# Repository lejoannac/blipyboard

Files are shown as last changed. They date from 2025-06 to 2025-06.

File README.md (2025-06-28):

# blipyboard
An 8 key macropad with an OLED screen and potentiometer for HackPad. It also has 8 SK6812 leds for lighting and utilizes custom KMK firmware. <br>

Screenshot 2025-06-27 at 11 23 31 PM

# **CAD Model**
Screenshot 2025-06-27 at 9 58 29 PM<br>
Designed and Modeled using Fusion 360

# **Schematic**
Screenshot 2025-06-27 at 10 01 06 PM

# **PCB**
Screenshot 2025-06-27 at 10 17 19 PM<br>
Schematic and PCB created using KiCad

# **BOM**
8x Cherry MX Switches<br>
9x 1N4148 Diodes<br>
8x SK6812 Mini LED<br>
8x Keycaps<br>
1x Rotary Encoder with push button<br>
1x 0.91" OLED Display (128x32)<br>
1x XIAO-RP2040 microcontroller<br>
4x M3x10mm screws<br>
1x Custom PCB<br>
1x 1kg spool of white filament from Amazon<br>
I will print my own case

# **Inspiration/Challenges**
I created this macropad to learn more about hardware and firmware creation. I wanted to be able to perform my most used functions with singular key presses such as copy/paste and inserting long strings. While working on this hackpad, I encountered issues with the firmware, the pcb, and 3d models associated with the footprints. By looking at other people's submissions and asking for help on slack, I overcame these issues. In the future I want to learn how to integrate QMK firmware and add more advanced animations for the OLED.

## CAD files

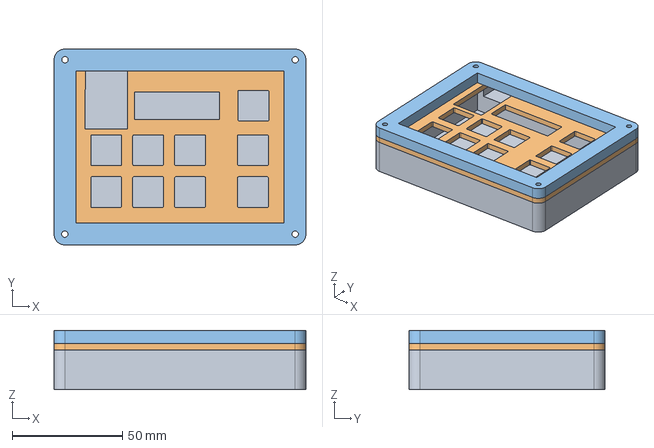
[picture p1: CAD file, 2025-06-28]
cad/blipyboard_complete.step
114.5 x 89.1 x 27.0 mm

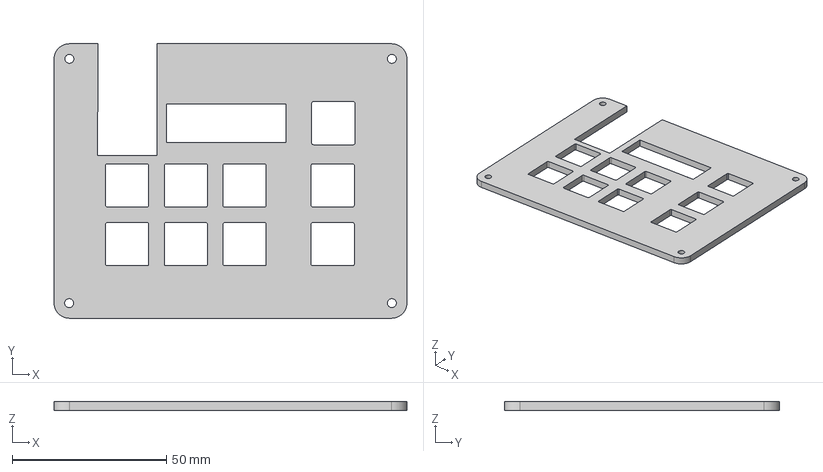
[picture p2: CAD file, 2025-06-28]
cad/plate.step
114.5 x 89.1 x 3.00 mm

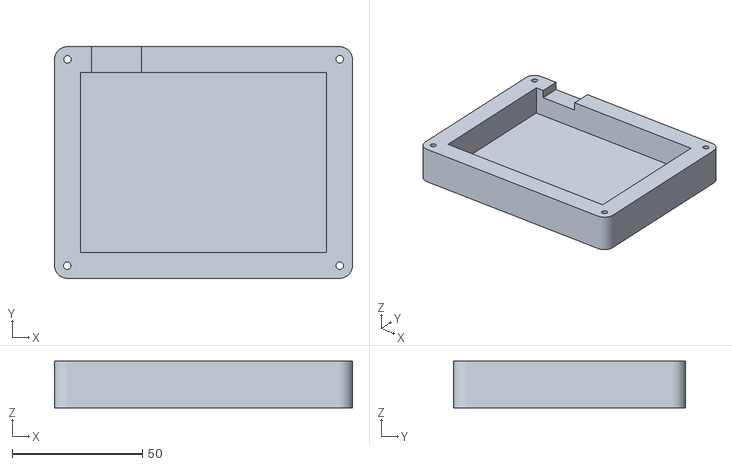
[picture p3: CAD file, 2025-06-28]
production/bottom.stl
114.5 x 89.1 x 18.0

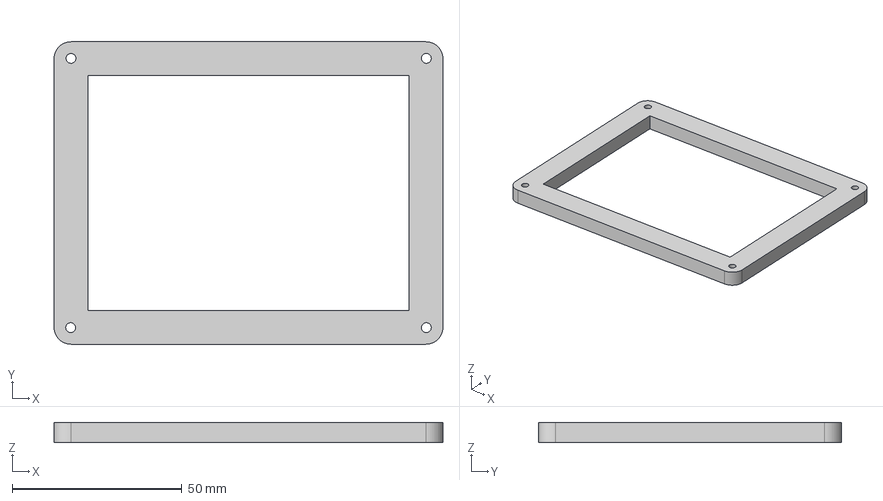
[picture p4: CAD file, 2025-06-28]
cad/top.step
114.5 x 89.1 x 6.00 mm

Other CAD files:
production/plate.stl
production/top.stl
cad/bottom.step

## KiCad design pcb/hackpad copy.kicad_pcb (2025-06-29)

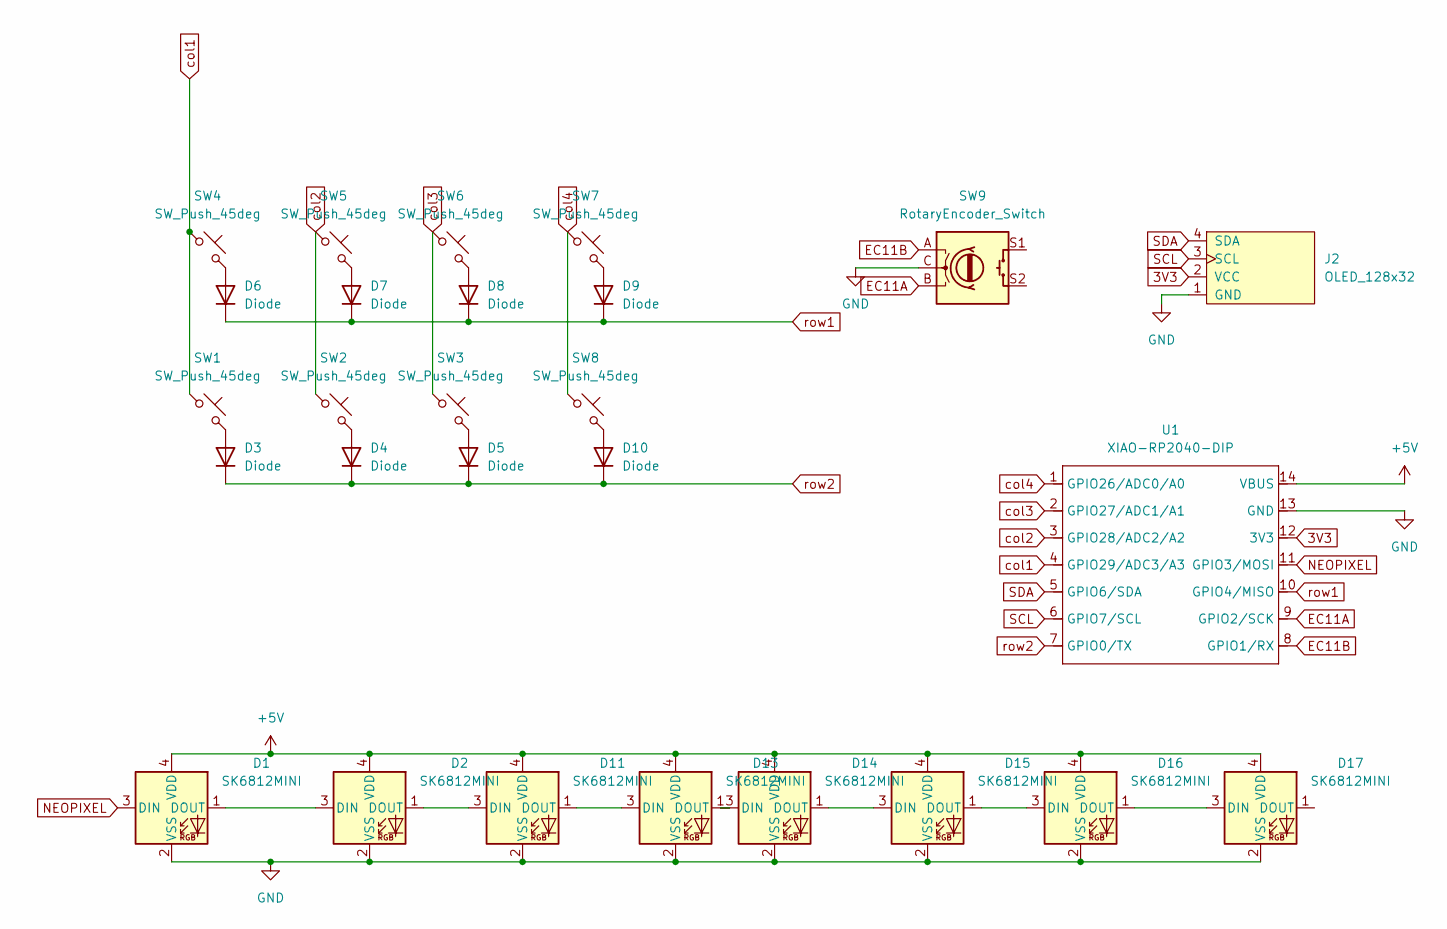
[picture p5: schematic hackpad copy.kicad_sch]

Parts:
D1, D2, D11, D13, D14, D15, D16, D17: SK6812MINI; LED_SK6812MINI_PLCC4_3.5x3.5mm_P1.75mm
D3, D4, D5, D6, D7, D8, D9, D10: Diode; D_DO-35_SOD27_P7.62mm_Horizontal
J2: OLED_128x32
SW1, SW2, SW3, SW4, SW5, SW6, SW7, SW8: SW_Push_45deg; SW_Cherry_MX_1.00u_PCB
SW9: RotaryEncoder_Switch; RotaryEncoder_Alps_EC11E-Switch_Vertical_H20mm
U1: XIAO-RP2040-DIP

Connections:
3V3: J2.2 (VCC), U1.12 (3V3)
+5V: D1.4 (VDD), D2.4 (VDD), D11.4 (VDD), D13.4 (VDD), D14.4 (VDD), D15.4 (VDD), D16.4 (VDD), D17.4 (VDD), U1.14 (VBUS)
EC11A: SW9.B, U1.9 (GPIO2/SCK)
EC11B: SW9.A, U1.8 (GPIO1/RX)
GND: D1.2 (VSS), D2.2 (VSS), D11.2 (VSS), D13.2 (VSS), D14.2 (VSS), D15.2 (VSS), D16.2 (VSS), D17.2 (VSS), J2.1 (GND), SW9.C, U1.13 (GND)
NEOPIXEL: D1.3 (DIN), U1.11 (GPIO3/MOSI)
unnamed: D1.1 (DOUT), D2.3 (DIN)
unnamed: D3.2 (A), SW1.2
unnamed: D4.2 (A), SW2.2
unnamed: D5.2 (A), SW3.2
unnamed: D6.2 (A), SW4.2
unnamed: D7.2 (A), SW5.2
unnamed: D8.2 (A), SW6.2
unnamed: D9.2 (A), SW7.2
unnamed: D10.2 (A), SW8.2
unnamed: D2.1 (DOUT), D11.3 (DIN)
unnamed: D11.1 (DOUT), D13.3 (DIN)
unnamed: D13.1 (DOUT), D14.3 (DIN)
unnamed: D14.1 (DOUT), D15.3 (DIN)
unnamed: D15.1 (DOUT), D16.3 (DIN)
unnamed: D16.1 (DOUT), D17.3 (DIN)
SCL: J2.3 (SCL), U1.6 (GPIO7/SCL)
SDA: J2.4 (SDA), U1.5 (GPIO6/SDA)
col1: SW1.1, SW4.1, U1.4 (GPIO29/ADC3/A3)
col2: SW2.1, SW5.1, U1.3 (GPIO28/ADC2/A2)
col3: SW3.1, SW6.1, U1.2 (GPIO27/ADC1/A1)
col4: SW7.1, SW8.1, U1.1 (GPIO26/ADC0/A0)
row1: D6.1 (K), D7.1 (K), D8.1 (K), D9.1 (K), U1.10 (GPIO4/MISO)
row2: D3.1 (K), D4.1 (K), D5.1 (K), D10.1 (K), U1.7 (GPIO0/TX)

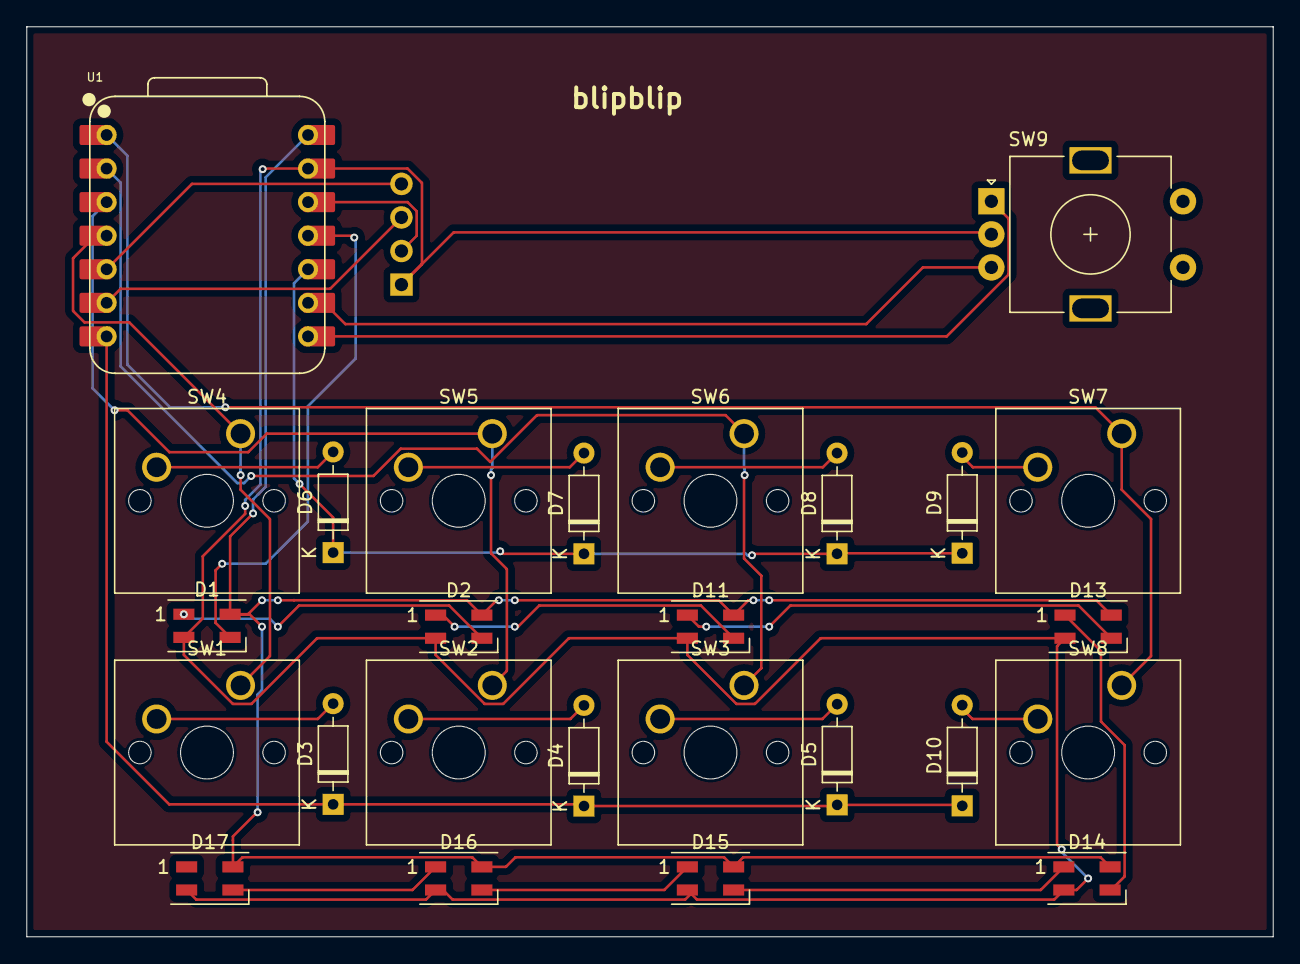
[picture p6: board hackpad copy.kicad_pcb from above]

Board: 2 copper layers, 94.3 x 68.9 mm, 27 parts (0 on the bottom side), 29 nets.

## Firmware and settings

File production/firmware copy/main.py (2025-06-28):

# You import all the IOs of your board
import board
import busio

# These are imports from the kmk library
from kmk.kmk_keyboard import KMKKeyboard
from kmk.scanners.keypad import KeysScanner
from kmk.keys import KC
from kmk.modules.macros import Press, Release, Tap, Macros
from kmk.modules.encoder import EncoderHandler
from kmk.extensions.mouse_keys import MouseKeys
from kmk.extensions.rgb import RGB
from kmk.extensions.display.ssd1306 import SSD1306
from kmk.extensions.display import Display, ImageEntry, TextEntry
from kmk.scanners.matrix import MatrixScanner


col1 = board.GP29
col2 = board.GP28
col3 = board.GP27
col4 = board.GP26
row1 = board.GP4
row2 = board.GP0
SDA = board.GP6
SCL = board.GP7
EC11A = board.GP2
EC11B = board.GP1

# This is the main instance of your keyboard
keyboard = KMKKeyboard()
mouse_keys = MouseKeys()
keyboard.extensions.append(mouse_keys)

# Add the macro extension
macros = Macros()
keyboard.modules.append(macros)

encoder_handler = EncoderHandler()

keyboard.modules.append(encoder_handler)
encoder_handler.pins = ((EC11A, EC11B),)
encoder_handler.map = [((KC.VOLU, KC.VOLD),)]

rgb = RGB(pixel_pin=board.GP3, 
          num_pixels=8, 
          rgb_order=(1,0,2),
          
          )
keyboard.extensions.append(rgb)

i2c_bus = busio.I2C(SCL, SDA)
driver = SSD1306(i2c=i2c_bus)

display = Display(
    # Mandatory:
    display=driver,
    # Optional:
    width=128, # screen size
    height=32, # screen size
    flip = False, # flips your display content
    flip_left = False, # flips your display content on left side split
    flip_right = False, # flips your display content on right side split
    brightness=1, # initial screen brightness level
)

display.entries = [
    ImageEntry(image="me.bmp", x=0, y=0, layer=0),
]
keyboard.extensions.append(display)


# Define your pins here!
ROW_PINS = [row1, row2]
COL_PINS = [col1, col2, col3, col4]


keyboard.matrix = MatrixScanner(
    columns=COL_PINS,
    rows=ROW_PINS,
)

keyboard.keymap = [
    [
        KC.MPRV, KC.MPLY, KC.MNXT, MouseKeys.LEFT_BUTTON,
        KC.LCTL(KC.C), KC.LCTL(KC.V), KC.MACRO("jxcai534@gmail.com"), MouseKeys.LEFT_BUTTON,
    ]
]

# Here you define the buttons corresponding to the pins
# Look here for keycodes: https://github.com/KMKfw/kmk_firmware/blob/main/docs/en/keycodes.md
# And here for macros: https://github.com/KMKfw/kmk_firmware/blob/main/docs/en/macros.md


# Start kmk!
if __name__ == '__main__':
    keyboard.go()

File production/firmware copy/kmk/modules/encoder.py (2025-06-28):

# See docs/encoder.md for how to use

import busio
import digitalio
from supervisor import ticks_ms

from kmk.modules import Module
from kmk.utils import Debug

debug = Debug(__name__)

# NB : not using rotaryio as it requires the pins to be consecutive


class BaseEncoder:

    VELOCITY_MODE = True

    def __init__(self, is_inverted=False, divisor=4):

        self.is_inverted = is_inverted
        self.divisor = divisor

        self._state = None
        self._start_state = None
        self._direction = None
        self._pos = 0
        self._button_state = True
        self._button_held = None
        self._velocity = 0

        self._movement = 0
        self._timestamp = ticks_ms()

        # callback functions on events. Need to be defined externally
        self.on_move_do = None
        self.on_button_do = None

    def get_state(self):
        return {
            'direction': self.is_inverted and -self._direction or self._direction,
            'position': self.is_inverted and -self._pos or self._pos,
            'is_pressed': not self._button_state,
            'velocity': self._velocity,
        }

        # Called in a loop to refresh encoder state

    def update_state(self):
        # Rotation events
        new_state = (self.pin_a.get_value(), self.pin_b.get_value())

        if new_state != self._state:
            # encoder moved
            self._movement += 1
            # false / false and true / true are common half steps
            # looking on the step just before helps determining
            # the direction
            if new_state[0] == new_state[1] and self._state[0] != self._state[1]:
                if new_state[1] == self._state[0]:
                    self._direction = 1
                else:
                    self._direction = -1

            # when the encoder settles on a position (every 2 steps)
            if new_state[0] == new_state[1]:
                # an encoder returned to the previous
                # position halfway, cancel rotation
                if (
                    self._start_state[0] == new_state[0]
                    and self._start_state[1] == new_state[1]
                    and self._movement <= 2
                ):
                    self._movement = 0
                    self._direction = 0

                # when the encoder made a full loop according to its divisor
                elif self._movement >= self.divisor - 1:
                    # 1 full step is 4 movements (2 for high-resolution encoder),
                    # however, when rotated quickly, some steps may be missed.
                    # This makes it behave more naturally
                    real_movement = self._movement // self.divisor
                    self._pos += self._direction * real_movement
                    if self.on_move_do is not None:
                        for i in range(real_movement):
                            self.on_move_do(self.get_state())

                    # Rotation finished, reset to identify new movement
                    self._movement = 0
                    self._direction = 0
                    self._start_state = new_state

            self._state = new_state

        # Velocity
        self.velocity_event()

        # Button event
        self.button_event()

    def velocity_event(self):
        if self.VELOCITY_MODE:
            new_timestamp = ticks_ms()
            self._velocity = new_timestamp - self._timestamp
            self._timestamp = new_timestamp

    def button_event(self):
        raise NotImplementedError('subclasses must override button_event()!')

    # return knob velocity as milliseconds between position changes (detents)
    # for backwards compatibility
    def vel_report(self):
        return self._velocity


class GPIOEncoder(BaseEncoder):
    def __init__(
        self,
        pin_a,
        pin_b,
        pin_button=None,
        is_inverted=False,
        divisor=None,
        button_pull=digitalio.Pull.UP,
    ):
        super().__init__(is_inverted)

        # Divisor can be 4 or 2 depending on whether the detent
        # on the encoder is defined by 2 or 4 pulses
        self.divisor = divisor

        self.pin_a = EncoderPin(pin_a)
        self.pin_b = EncoderPin(pin_b)
        if pin_button:
            self.pin_button = EncoderPin(pin_button, button_type=True, pull=button_pull)
        else:
            self.pin_button = None

        self._state = (self.pin_a.get_value(), self.pin_b.get_value())
        self._start_state = self._state

    def button_event(self):
        if self.pin_button:
            new_button_state = self.pin_button.get_value()
            if new_button_state != self._button_state:
                self._button_state = new_button_state
                if self.on_button_do is not None:
                    self.on_button_do(self.get_state())


class EncoderPin:
    def __init__(self, pin, button_type=False, pull=digitalio.Pull.UP):
        self.pin = pin
        self.button_type = button_type
        self.pull = pull
        self.prepare_pin()

    def prepare_pin(self):
        if self.pin is not None:
            if isinstance(self.pin, digitalio.DigitalInOut):
                self.io = self.pin
            else:
                self.io = digitalio.DigitalInOut(self.pin)
            self.io.direction = digitalio.Direction.INPUT
            self.io.pull = self.pull
        else:
            self.io = None

    def get_value(self):
        io = self.io
        result = io.value
        if digitalio.Pull.UP != io.pull:
            result = not result
        return result
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

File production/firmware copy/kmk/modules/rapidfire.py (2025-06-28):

from micropython import const

from random import randint

from kmk.keys import Key, make_argumented_key
from kmk.modules import Module
from kmk.utils import Debug

debug = Debug(__name__)

_INACTIVE = const(0)
_HOLD = const(1)
_ACTIVE = const(2)


class RapidFireKey(Key):
    def __init__(
        self,
        key,
        interval=100,
        timeout=200,
        enable_interval_randomization=False,
        randomization_magnitude=15,
        toggle=False,
        **kwargs,
    ):
        super().__init__(**kwargs)
        self.key = key
        self.interval = interval
        self.timeout = timeout
        self.enable_interval_randomization = enable_interval_randomization
        self.randomization_magnitude = randomization_magnitude
        self.toggle = toggle
        self._state = _INACTIVE
        self._timeout = None


class RapidFire(Module):
    def __init__(self):
        make_argumented_key(
            names=('RF',),
            constructor=RapidFireKey,
            on_press=self._rf_pressed,
            on_release=self._rf_released,
        )

    def _on_timer_timeout(self, key, keyboard):
        if key._state == _HOLD:
            key._state = _ACTIVE
            keyboard.remove_key(key.key)
            key._timeout = keyboard.set_timeout(
                1, lambda: self._on_timer_timeout(key, keyboard)
            )
            return

        keyboard.add_key(key.key)
        keyboard.set_timeout(1, lambda: keyboard.remove_key(key.key))

        interval = key.interval
        if key.enable_interval_randomization:
            interval += randint(
                -key.randomization_magnitude, key.randomization_magnitude
            )
        key._timeout = keyboard.set_timeout(
            interval, lambda: self._on_timer_timeout(key, keyboard)
        )

        if debug.enabled:
            debug(key.key, ' @', interval, 'ms')

    def _rf_pressed(self, key, keyboard, *args, **kwargs):
        if key._state == _ACTIVE:
            self._deactivate_key(key, keyboard)
            return

        keyboard.add_key(key.key)
        key._state = _HOLD
        key._timeout = keyboard.set_timeout(
            key.timeout, lambda: self._on_timer_timeout(key, keyboard)
        )

    def _rf_released(self, key, keyboard, *args, **kwargs):
        if key._state == _ACTIVE:
            if key.toggle:
                return
            key._state = _INACTIVE
        elif key._state == _INACTIVE:
            return
        else:
            keyboard.remove_key(key.key)

        self._deactivate_key(key, keyboard)

    def _deactivate_key(self, key, keyboard):
        keyboard.cancel_timeout(key._timeout)
        key._state = _INACTIVE
        key._timeout = None

    def during_bootup(self, keyboard):
        return

    def before_matrix_scan(self, keyboard):
        return

    def before_hid_send(self, keyboard):
        return

    def after_hid_send(self, keyboard):
        return

    def on_powersave_enable(self, keyboard):
        return

    def on_powersave_disable(self, keyboard):
        return

    def after_matrix_scan(self, keyboard):
        return
